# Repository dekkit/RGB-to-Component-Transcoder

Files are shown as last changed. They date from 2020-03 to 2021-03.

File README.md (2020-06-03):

# Dek's RGB-to-Component-Transcoder
A DIY RGB to Component Video Transcoder to make your own video conversion boxes. 

This schematic and associated PCB does not do any upscaling and is designed to support old CRT TVs that only have component video inputs (not RGB scart like in many european countries) and primarily as way to open up more output options for retro consoles using an external method (rather needing to directly modify the internal hardware).   

This schematic will not upscale a 240p signal. Many LCD tvs will not display a 240p picture through Component video in.

New versions (schematic, pcb files, test results etc) can be found here in the code repository
https://github.com/dekkit/RGB-to-Component-Transcoder

Versions: 
VA01  (initial prototype),
VA02  (fixes, after initial tests),   
VAxx  (future versions will be in their own folders)

If you want to want to get a bunch of PCBs manufactured - simply use the latest GERBER zip (ie Gerber_PCB_2020-04-10 17_26_57.zip) file.  Most manufacturers will provide an instant quote and typically is only be a few dollars plus postage (postage is most expensive part).   Or  use the schematic to build your own breadboard version.

Please feel free to copy, adapt and use as appropriate (public domain). If you do improve on this design, please provide an acknowledgement,  drop me a note / create an issue to let me know and share your results.

If you would like to develop your own version (customised for your specific video device, make a smaller SMD version), or simply to poke around to help further your own understanding  (pick up on any errors too!) - I used the free app EasyEDA - I've opened up the project to make it easiser to clone and adapt (see https://easyeda.com/dekkit/rgb-to-component-transcoder)

Dek.
29/5/2020

Acknowledgements to Ace, Zebidee and all variations available on the web which helped me get this far.
Also to https://www.retrorgb.com/ for most useful info on LM1881 and THS amps - it's an excellent resource highly recommended site.

FURTHER BACKGROUND

This schematic was intended to be used for consumer CRT TVs as another way to support RGB (particulary in retro video game consoles and arcade setups where crt tubes are getting harder to find/replace). It is designed to be used as an external device (outside of the system) rather be used as an internal mod.

Includes
- Audio pass through (to support the development of custom retro console cables)
- Additional variable resistors (trim pots) to attenuate incoming RGB signals and create an all-in-one style plug (useful for per retro console customisations ie snes pal).
- Composite Video to Composite Sync (to extract csync from normal composite video, in case a system does not natively output csync - like Super Nintentdo pal, or if you want to create an RGB Scart to Component transcoder) - alternatively you can also extract sync from luma or if you already have csync signal add a jumper wire.
- Mostly through-hole components to make it easier to assemble (except for the THS amp).

Design Note(s)

- Designed primarily as an external unit, input are assumed to be 75 ohm signals (hence the use of 75R resitors to ground). You may need to remove these if you intend to adapt this pcb and use it intenally.
- For arcade boards you will need to attenuate the RGB signals to a level that a normal consumer CRT will accept (ie 3-5V p-p down to 0.7V p-p) - this can be done altering the resistor values (google arcade to scart for more info and for recommended adjustments and warning -  this may damage your video hardware if not done correctly).

Materials - i've included the Bill of materials as a downloadable CSV.
- Used 1/4 watt resistors 5% (either ceramic or metallic - though many TV mods use ceramic, so use cermic if possible)
- Low voltage components are acceptable (ie I've been using 6.3v for the electrolytic cap without any issues)
- Monolythic ceramic capacitors were used (104, and 105 - again use metallic ones if ceramic is unavailable).

It has been designed to fit in a small DIY project box of dimensions 10cm x 6cm x 2.5cm (with screw holes aligned).  You can find these easily online or you can arrange a 3D print.

Initial successful testing (on version VA01 19/4/2020):
Snes (PAL), Dreamcast (NTSC), Arcade 60-in-1 Jamma PCB, Sega Saturn (PAL), Sega MegaDrive2 (PAL).

Note - on Playstation 1 (PAL) - I found this required a seperate 5v supply (as the 5v pin dropped to 3.18v underload) 

Warning
No Warranty provided /use at own risk. Will not be held liable for any damage (its free after all!).
Use quality video cables   (cheap imported video cables have all sorts of video interferences - keep cables short too!).  Also please review the issues section before building for any identified issues / work-arounds.

Please share, clone, improve and share again (pay it forward) - that way we can all benefit. 

This schematic and pcb(s) have been based on the many designs found on the web using the BA7230 chip and from plenty of own my trials and testing the outputs until i found a method and design i was comfortable with it.  Project was initiated after discovering that one of my crts was unable to be RGB modded but could be modded to support component video.

Hope you find it as useful as I have.

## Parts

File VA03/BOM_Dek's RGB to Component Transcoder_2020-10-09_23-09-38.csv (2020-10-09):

ID | Name | Designator | Footprint | Quantity | Manufacturer Part | Manufacturer | Supplier | Supplier Part | value(Ω)
1 | LM1881 | U3 | LM1881 | 1
2 | THS7374 | U2 | TTSOP-14 | 1 | THS7314DRG4 | TI | LCSC | C24990
3 | 10u | C5 | CAP-D3.0XF1.5 | 1
4 | 0.047u | C4 | RAD-0.2 | 1
5 | 1u | C13,C14,C11,C12,C7,C6,C8 | RAD-0.2 | 7
6 | 0.1u | C3,C1,C9,C10,C2,C15,C16 | RAD-0.2 | 7
7 | BA7230LS | U1 | SZIP24 | 1
8 | 75 | R13,R2,R3,R8,R9,R10,R1 | AXIAL-0.3 | 7
9 | 330 | R12 | AXIAL-0.3 | 1
10 | 680k | R11 | AXIAL-0.3 | 1
11 | 1k | R4,R7 | AXIAL-0.3 | 2
12 | 2M2 | R5,R6 | AXIAL-0.3 | 2
13 | 140 | R14 | AXIAL-0.3 | 1
14 | R_3386P_US | RP1,RP2,RP3 | RES-ADJ-TH_3386P | 3 |  |  | LCSC |  | 10K
15 | PAD | U7,U16,U15,U14,U4,U5,U6,U13,U8,U9,U10,U11,U12 | PAD3X4 | 13 | New SchematicLib

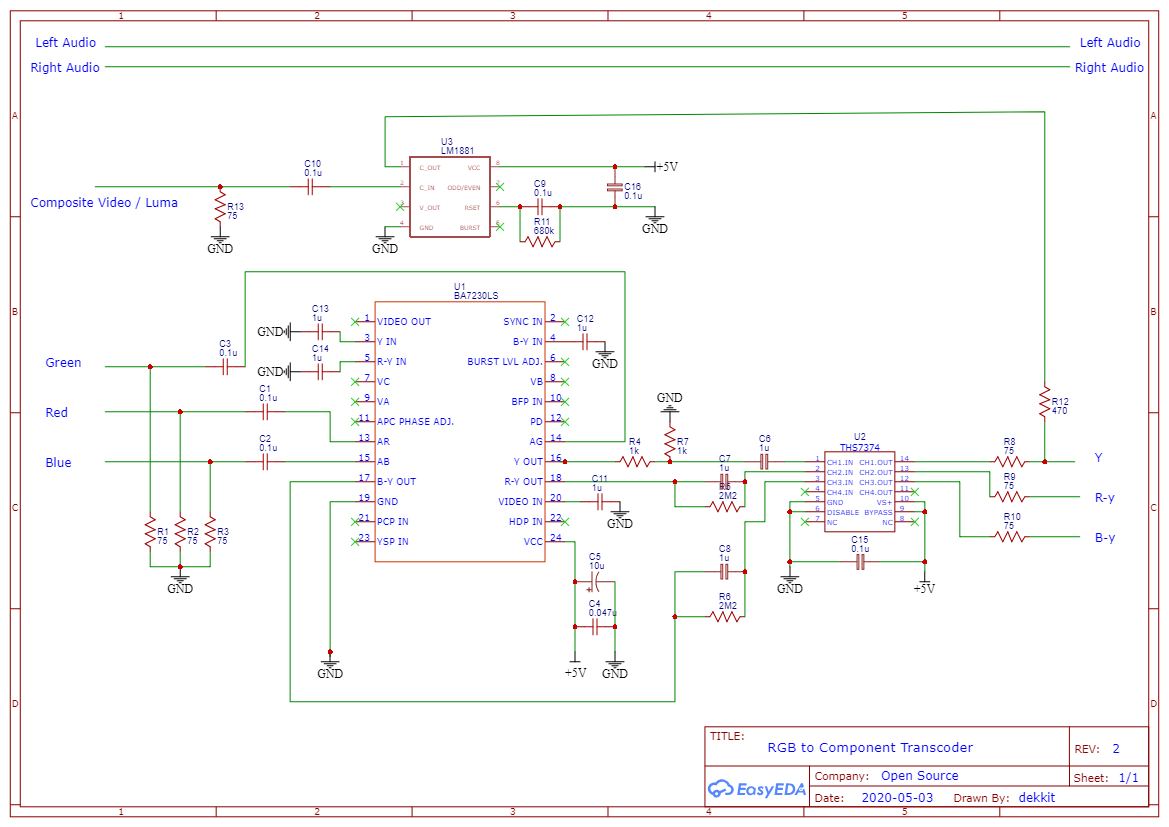
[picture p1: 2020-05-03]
RGB2Component_Dek_v2.00.png

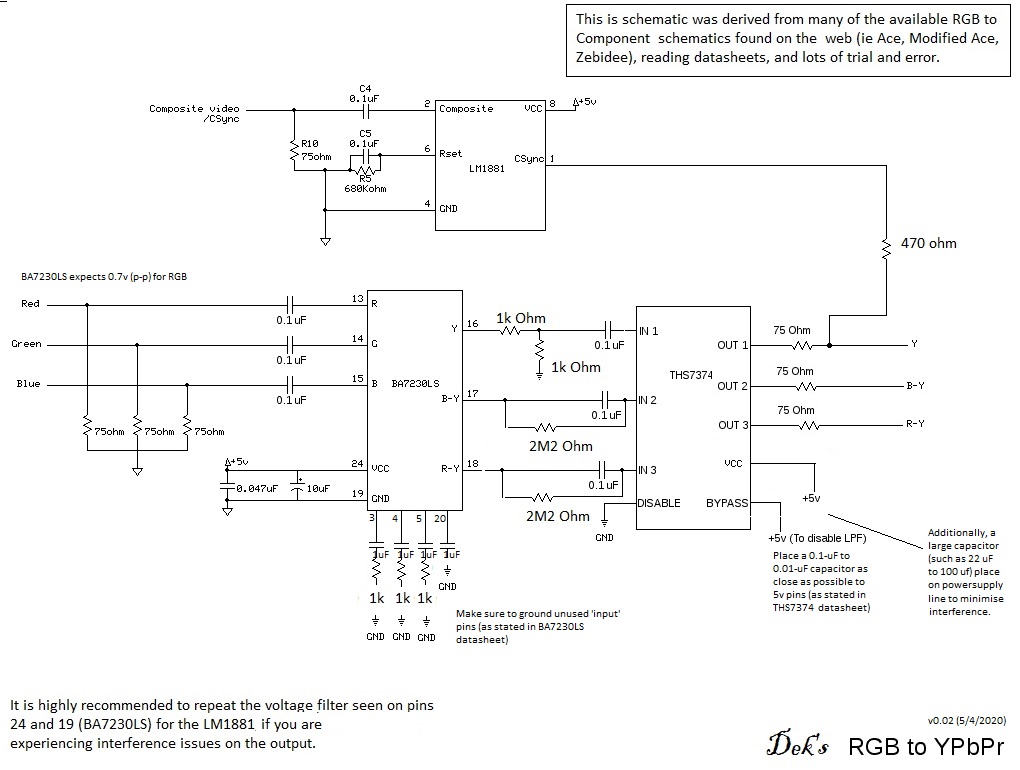
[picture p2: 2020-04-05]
RGB2Component_Dek_v0.02.jpg

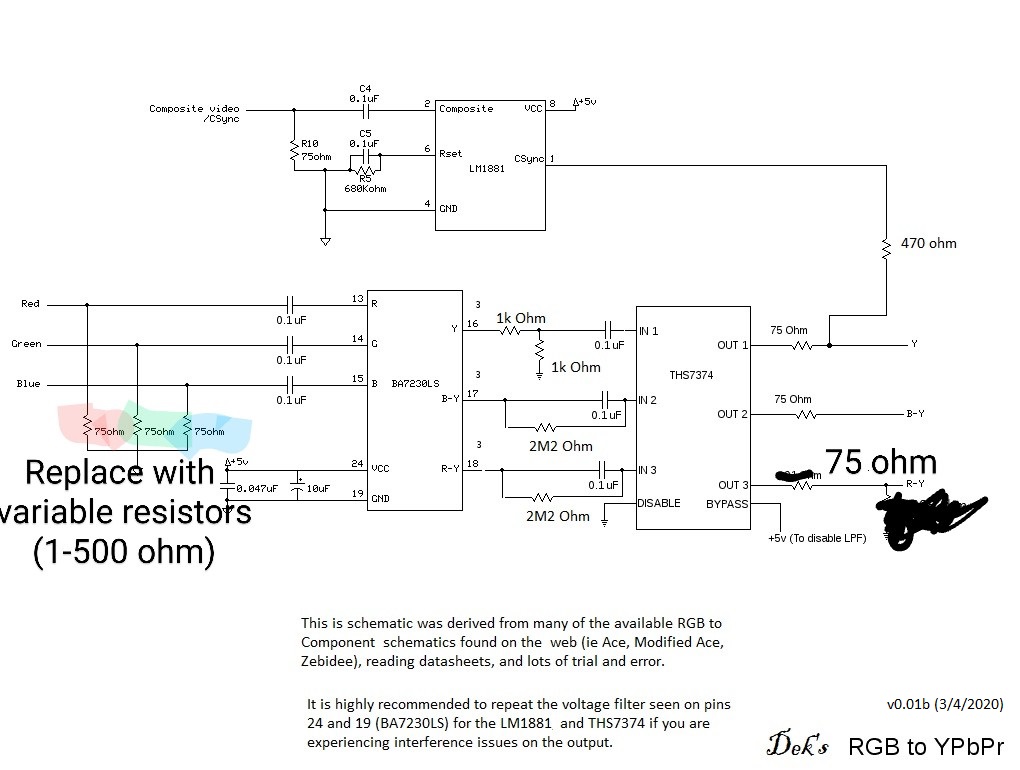
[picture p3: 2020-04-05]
RGB2Component_Dek_v0.01_b.jpg

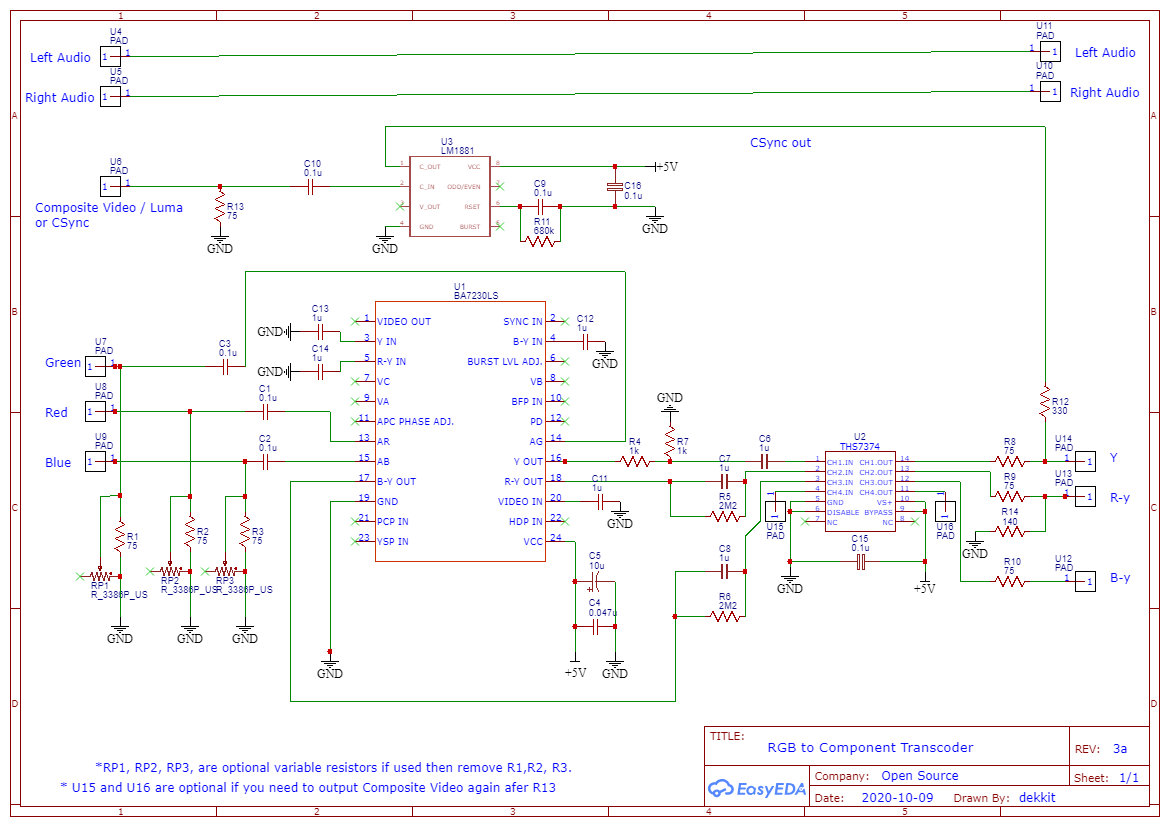
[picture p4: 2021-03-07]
Schematic_Dek's RGB to Component Transcoder_2021-03-08.png

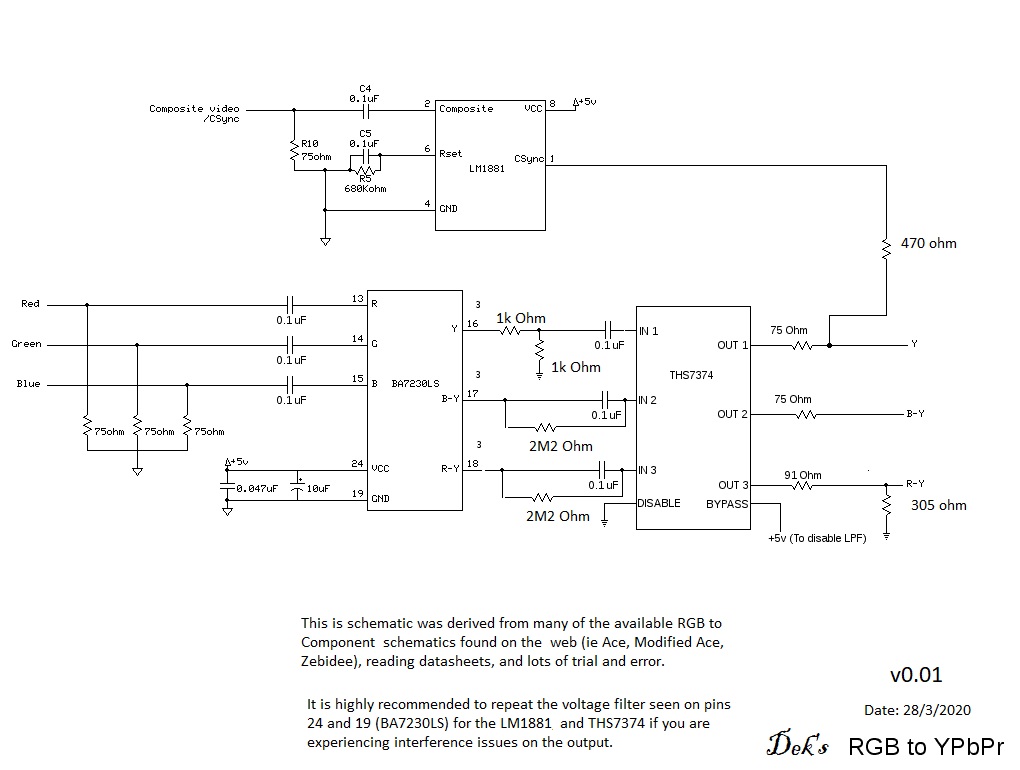
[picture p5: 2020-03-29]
RGB2Component_Dek_v0.01.jpg

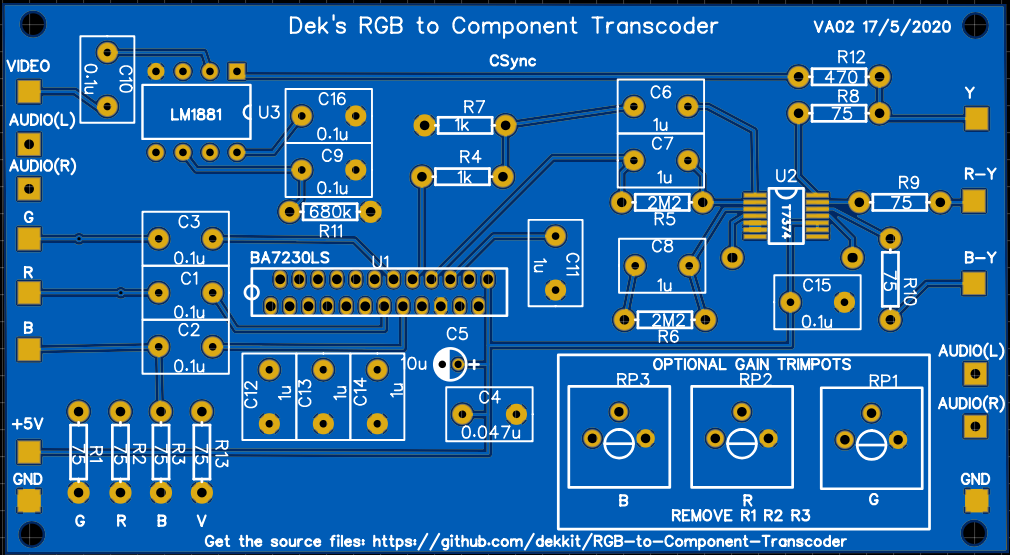
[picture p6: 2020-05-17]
VA02/PCB_PHOTO_RGB to Component Transcoder_2020-05-17_21-51-17.png

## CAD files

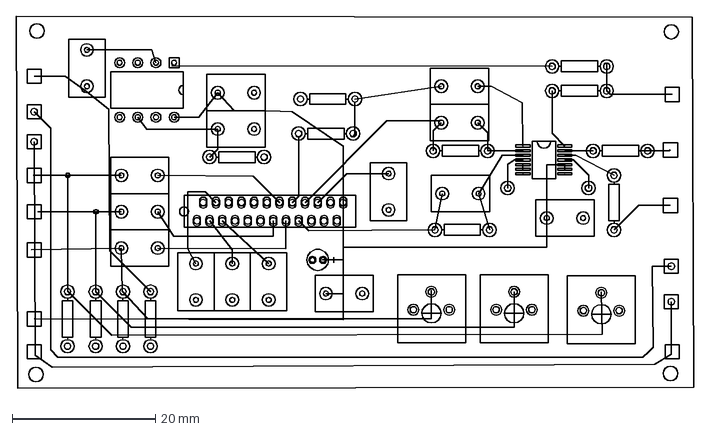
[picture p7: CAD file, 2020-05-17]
VA02/PCB_2020-04-10 17_26_57_2020-05-17_21-50-01.dxf
94.7 x 52.5 mm

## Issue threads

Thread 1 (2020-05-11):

Version 1.0 / VA01 (19/4/2020) - Issues and post-fixes

dekkit, 2020-05-11:
A collection of fixes for the first protoype pcb version (as i find them) and also what is needed to correct it.

_**VA01 (19/4/2020) - post production fixes**_

-  VIDEO (in) did not have a 75R to ground.

This is needed to attenuate an external composite video signal and was inadventently ommited when transposing the schematic into a proper tool! To correct this, add one side of a 75R resistor to the left side of C10, with the other side of the resistor to the ground pin of the LM1881. (Refer to LM1881 datasheet if unsure of which pin, alternatively create a jumper wire to the ground pad).

- Output label B-Y is incorrect.

This error was introduced late in the process when reducing the size of the pcb and rearranging parts and not picked up until too late. This should be labelled  R-Y, ensure you connect R-Y (red) cable/socket to this pad.

- Output label R-Y is incorrect.

As above, this should be labelled  B-Y. Ensure you connect the B-Y (blue) cable/socket to this pad.

- Monoloythic Capacitors are wider (~5mm) than through holes provided (~2.5mm).

An incorrect stencil was used during design. Bend cap legs to suit. ;)

- R12 resistor value is incorrect, instead of 470 or i1k2 ohm use r12= 330ohm (330R)!

While a value between 470 ohm to 1200 ohm resistor works - further testing has discovered that lm1881 is typically only outputting between 2.8-3.2v under typical use (originally it was assumed a 5v signal from the LM1881 would need to be pulled down to 0.3v p-p before combining with Y).

To ensure more compatibility with more CRT TVs the lower value of 330ohm is preferred. This typically generated a sync pulse of 260 to 288mv which is much closer to spec under more testing and closer review under a scope.

 If you get a rolling picture, you may need to alter this resistor value at R12 (fyi using a 1k2 resulted in a sync signal closer to 100-150mv whick works but not ideal) - this has been updated in the VA03 schematic and pcb.

Closed 2023-04-27.

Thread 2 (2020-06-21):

Interference due to power source

dekkit, 2020-06-21:
5v power source will have an effect on video output interference.

If you see a rolling ripple effect on your video output check the quality and setup of your power source.

This effect is shown as below:
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

This is an effect can be caused a few ways - one is via a common ground loop issue, another is the other due to 'AC ripple' which will create signal noise regardless of the quality or length of your cables, and can also be caused by using very poor quality (often very cheap) switching power supplies found on online market places.

Resolution:

Either find:
- cleaner power source (ie a 5v portable mobile phone battery power supply is a quick fix using a chopped usb cable)
- a 5v dc to dc isolator (a small chip that separates the common ground)
- add a simple low pass filter to the 5v input
- add a smoothing capacitor to control for the ac ripple
- a Low Drop Output (LDO) voltage regulator to condition and clean the 5v signal (this will likely need additional capacitors and resistor).

Or use any combination of the above.  There are plenty of low pass filter designs on the web.

In most cases, I found just using a quality 5v mobile phone wall charger and cutting up a usb cable removed almost all of the noise.

Despite trying all sorts of power cleaning circuits on a very poor quality 5v power supply, it is much better to start with a quality 5v supply first.

Will consider adding to a future pcb revision.

Closed 2023-04-27.

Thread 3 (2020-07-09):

60 in 1 Jamma Arcade PCB - Conversion

dekkit, 2020-07-09:
As part of providing further examples, I thought id create an issue to cover my experience in converting one of these cheap 60 in 1 jamma arcade pcbs to output in YUV/ Component and update this initial post with refinements.

You may have seen these online for $40-60 in various forms:
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

They are a great collection of classic games that are emulated in a fpga really well.   As they can output in both Arcade 15hz and normal vga screen modes and are powered by molex connector - they are perfect for a conversion project like this.

Parts
1 x dek transcoder pcb (fully assembled with cables to tv etc)  - see below for specifics.
1 x  hdd sata power supply with molex connector (ie from a sata to usb kit) to power arcade board
1x quality mobile phone charger and usb cable you are confortable to chop up - to 5v power the transcoder pcb.
3 x 75 ohm resistors
1x 470 ohm resistor
1x Arcade joy stick (cheap sanwa clones work well)
3x arcade parts buttons (or whatever microswitches you want to substitute)
1x jamma  harness

Connecting arcade pcb to transcoder.  For this section you will need to reference the standard jamma harness pinout - easily found via google.

- You can do this one of two ways either via the vga port on the arcade pcb (using a female vga 15pin socket) or taking the rgb signals from the jamma harness.
- if you take the  rgb signals from the jamma harness pins, be sure to add a 75 ohm resistor in series for each r,g,b line before connecting to the rgb inputs of the transcoder pcb.  This arcade board seems output a lower than normal peak to peak voltage for each signal which is why low resistor values can be used.
- if you take the rgb signals from vga port on the arcade board you do not need to use these extra 75ohm resistors (as they are already on the arcade board)
The 75ohm resistors act as a voltage divider with the 75 ohm resistors on the transcoder pcb -  bringing the rgb signals into the 0.7 p-p range.
- csync is taken from jamma harness and i used a 470 ohm resistor in series before connecting to transcoder pcb (to bring it down to under 0.7 p-p) note: you can take csync from the vga port instead (pin 13 on vga is csync when the arcade board is set to 15hz) but you will still need the 470 ohm resistor.
- Audio left and right are wired directly from the jamma harness audio pins to the transcoder pcb.  Alternatively you can use the 3.5mm audio jack on the arcade board.
- You will need to wire up your joystick and buttons as per the standard jamma pins if you intend to play ;)

Considerations for the transcoder pcb:
- LM1881 is optional (incl. associated resistors etc) as you have csync being provided from the source.  You will need bridge the points on the transcoder pcb (see bridge symbol) where the lm1881 sits if you omit it.  Also you will not need the 470 ohm resistor on input in this case.

I kept the LM1881 in my version as it kept a more stable picture on my crt but it depends on how fussy your crt is.

I also amended the following resistor values:
R12 = 470 (470-500R seemed to give the most stable picture quality for arcade pcb)
R13 = not connected (no resistor needed as we are not attenuating the composite video input )

dekkit, 2020-07-09:
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

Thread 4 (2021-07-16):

Question — Gamma

partlyhuman, 2021-07-16:
Hi there! Thank you for sharing this design! I just built one of the V03A revisions, and I'm trying it out with an unmodified Genesis 2 (NTSC, VA1 revision). The colors look like maybe the gamma is way off, I'm wondering if you have any inkling what the issue could be. Comparing transcoded YPbPr first and composite for reference second:
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

One deviation from the design is I've used electrolytic instead of ceramic caps for the 1uF caps, placing them in the correct orientation (negative legs toward ground plate in the obvious cases, and as measured in the circuit via multimeter in other cases—turns out to be negative facing down or right in the V03a layout with the exception of the actual electrolytic cap C5).

I'll likely try building another from the ground up and see if I get the same results, but if you have any ideas for something to try, I would be happy to hear your thoughts. Thank you again! (Update: Built a second one and have the same result.)

partlyhuman, 2021-07-19:
This output colorspace may be specific to the Genesis. Used together with my RGB-modded PC Engine Duo, the results were terrific.  I've published a project box customized for the transcoder here https://www.thingiverse.com/thing:4912451

Thank you again for making your designs public!

dekkit, 2022-01-20:
Sorry for the delay in reply and thank you for sharing your 3d printable box design!

A few ideas, given it works for the duo, id check your cable for the genesis 2.  Ie make sure youre getting clean RGB signals (there may also be regional differences in pal vs ntsc scart cables).

Visually it looks like 'Green' input is under powered, likely on the input side from your pics.

Also check what you are feeding in for sync as that could be a considerarion (unlikely).

Color issues can also be result of the THS amp pins not making a solid connection with pads (tho unlikely given it works for another console)

Glad you were able to use, it was a great learning experience.

Closed 2021-07-19.

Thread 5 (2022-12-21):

Spec doesn't specify r value of trimpots rp1-rp3

ogg1e, 2022-12-21:
Just wondering what R value to use for the 3 trimpots?  100 ohm?

dekkit, 2023-04-27:
they aren't necessary, but 100 or 150 ohm trimpot should do it .

Note: The default resistors in are  75 ohm (for each colour) and is a typical convention used for video circuits, so it really depends on how much extra attenuation you need for your particular use case (ie colours are dull because your using an old arcade board and you want to use the trimpot to help give it a boost).

If you are not sure what you need, just omit the trimpots and stay with the fixed value 75 ohm resistor.

Closed 2023-04-27.

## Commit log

2020-04-03 Simplified removed./ replaced.resistors
    A further modification
    - change the output resistors from the ths7374 amp - simple 75ohm on each output
    - suggestion of variable pots on rgb in lines to adjust voltages for better color balance needed for some video game console outputs that may not fully conform to 0.7 p -p .
2020-04-05 Added additional notes and added grounding for unused pins.
2020-04-19 Updated for production of a PCB
    Drawn using EasyEDA (really easy to use btw!) - should be easier to follow, particularly with grounding unused pins of each IC chip.
2020-04-19 3D image of the PCB being developed for further testing
2020-05-03 Add files via upload
    Re-Added in 75ohm to ground for video in.
    Also fixed the labels for outputs... R-y and B-y (as they had been flipped in the PCB labels)
2020-05-03 Gerber PCB production files from version 2.0 (alpha)
    Please check before building from these.
    Known Issues
    The pitch for the Capacitors through hole is 2mm, when most mono caps is 5mm. This doesn't effect build as such (as legs can easily be bent to fit) but should be fixed eventually.
2020-05-17 Clean up and new version
    Clean up of file structure, added all files for latest vesion VA02 - to support local pcb production.
    [PCB_2020-04-10 17_26_57_2020-05-17_21-50-01.dxf]
2020-05-17 Bill of Materials (BOM)
    Resistors are 1/4 Watt
    Capacitors are ceramic monolythic (104 / 105)
    Electrolytic cap you only need v6.3
    [BOM_RGB to Component Transcoder_2020-05-17_21-46-46.csv]
2020-05-17 Updated based on latest PCB and EasyEDA repository
2020-05-28 Change to R12 resistor value from 470 to 1K2
2020-10-09 Updated PCB
    A number of amendments based on further testing to give improved output.
    R12=now 330 (as this gave the best results on most devices as LM1881 output was 2.8v to 3.2v)
    140R added to Y-r (to bring R-y more in balance with Y-b) - based on feedback, testing, and much investigation (many thanks to Zeb for working through this). This helps to resolve an underlying issue with with BA7230LS's color matrix.
    [BOM_Dek's RGB to Component Transcoder_2020-10-09_23-09-38.csv]
2021-03-07 fixed error on va3 - schematic and pcb
    Incorrectly had 140R to ground on B-y (this should of been on R-y)
